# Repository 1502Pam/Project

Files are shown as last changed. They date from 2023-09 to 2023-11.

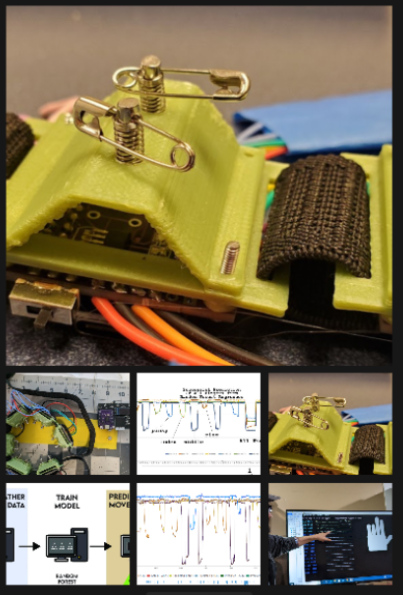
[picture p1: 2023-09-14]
Imágenes/muscle_finger.png

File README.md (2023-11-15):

# Equipo 12

#### Bienvenidos al repositorio del Equipo 12 del curso Fundamentos de Biodiseño

<image src ="Imágenes/foto_grupal_2.jpg"> 

## Tabla de contenido

- [Roles de los integrantes del proyecto](#Roles-de-los-integrantes-del-proyecto).
- [Análisis del caso clínico](#Análisis-del-caso-clínico).
- [Clínica de problemáticas en salud](#Clínica-de-problemáticas-en-salud).
- [Problemática](#Problemática).
- [Estado del arte científico](#Estado-del-arte-científico).
- [Estado del arte comercial](#Estado-del-arte-comercial).
- [Lista de requerimientos](#Lista-de-requerimientos).
- [Propuesta de solución](#Propuesta-de-solución).
- [Caja negra](#Caja-negra).
- [Esquema de funciones](#Esquema-de-funciones).
- [Matriz morfológica](#Matriz-morfológica).
- [Tabla de valoración](#Tabla-de-valoración).
- [Conclusión-del-CS](#Conclusión-del-CS).
- [Bocetos](#Bocetos).
- [Docentes del curso](#Docentes-del-curso).
- [Bibliografía](#Bibliografía).

## Roles de los integrantes del proyecto
- Chavez Rivas Allen Stirs (Planificador de la electrónica)
- Lazares Salcedo, Brayam Joe (Planificador de diseño de los planos del prototipo)
- Llanos Florian Dhiago Gustavo (Coordinador del grupo y planificador del modelado 3D del prototipado)
- Medina Burga Yuliana Abigail (Planificador de manufactura digital)
- Sanchez Valverde Mariel Linette (Planificador de programación)
- Vilchez Cotrina Pamela Nicole (Planificador del repositorio Github)

## Análisis del caso clínico

### A) Contexto

Según Global Burden of Disease (GBD)<sup>[1](https://vizhub.healthdata.org/gbd-results?params=gbd-api-2019-permalink/5ed2741ada3f6d3537da4bec76913a24)</sup>, existe una prevalencia mundial de amputaciones cercana a 500 millones de personas entre los periodos 1990 y 2019.

<image src ="Imágenes/B1.png"> 
   
###### Figura 1: Gráfica de prevalencia de amputaciones en personas mayores a 25 años desde 1990 hasta 2019 a nivel global. Obtenido del GBD

Inclusive los números han ido en crecimiento; por ende, se estima que, para este año 2023, la cifra habrá sobrepasado los 500 millones de personas mayores a 25 años con algún tipo de amputación.

<image src ="Imágenes/B2.png"> 
   
###### Figura 2: Gráfica de prevalencia del tipo de amputaciones en personas mayores a 25 años en el período 1990-2019 a nivel global. Obtenido del GBD

El tipo de amputación más común es en dedos, con una prevalencia que supera los 300 millones casos y que representa el 69.71% de las amputaciones totales, según los datos otorgados por el GBD. Además, la gráfica hace una clara diferencia entre los dedos y el pulgar, esto puede deberse a una mayor importancia del pulgar sobre los demás dedos.

<image src ="Imágenes/B3.png"> 

###### Figura 3: Gráfica de prevalencia en el período 1990-2019 e incidencia del año 2019 de amputaciones en el pulgar a nivel global. Obtenido del GBD

En cuanto a la estadística de amputaciones del pulgar, el 21.8% de amputaciones totales de dedos son de pulgares. Además, la incidencia de este tipo de amputación, en el año 2019, fue superior a un millón a nivel global.

<image src ="Imágenes/B4.png"> 

###### Figura 4: Gráfica de prevalencia en el período 1990-2019 e incidencia del año 2019 de amputaciones del pulgar en Latinoamérica. Obtenido del GBD

A nivel de Latinoamérica, se tiene una prevalencia superior a los 9 millones y una incidencia, en 2019, de 128000 personas con amputaciones del pulgar. A partir de la gráfica, se aprecia que la zona andina de países como Perú, Bolivia y Ecuador tiene la menor estadística; no obstante, el tamaño de población de cada una es inferior respecto al resto de regiones latinoamericanas.

<image src ="Imágenes/B5.png"> 

###### Figura 5: Prevalencia de amputaciones del pulgar a nivel global en el período 1990-2019. Obtenido del GBD.
   
En el Perú, existe una prevalencia de 400 mil personas con amputaciones de dedo en el período 1990-2019; además, según el Boletín Estadístico Mensual de Notificaciones de accidentes de Trabajo, Incidentes Peligrosos y Enfermedades Ocupacionales, durante el mes de abril del 2023, se reportaron 2390 personas que sufrieron accidentes de trabajo, destacando los siguientes datos<sup>[2](https://cdn.www.gob.pe/uploads/document/file/4811002/SAT_MARZO_2023_opt.pdf?v=1688742640), [3](https://cdn.www.gob.pe/uploads/document/file/4811381/SAT_ABRIL_2023_opt.pdf?v=1688744828)</sup> : 

| Accidentes de trabajo | Especificación | Cantidad de personas afectadas | Fecha de registro de datos |
| --- | --- | --- | --- |
| Agente causante  | Generador de energía excepto motores eléctricos | 10 | Marzo 2023 |
| | Contacto con la corriente eléctrica  | 13 | Marzo 2023 |
| Naturaleza de la lesión | Amputación | 20 | Marzo 2023 |
| Parte del cuerpo afectada | Dedos de la mano | 411 | Abril 2023 |
|  | Mano (excepción de los dedos solos) | 139 | Abril 2023 |
| Naturaleza de la lesión | Amputación | 13 | Abril 2023 |
| Agente causante | Instalaciones eléctricas, incluidos los motores eléctricos pero con exclusión de las herramientas eléctricas manuales | 1 | Abril 2023 |
###### Tabla 1: Tabla de accidentes de trabajo del mes de abril y marzo 2023. Elaboración ia en base a datos obtenidos del Ministerio de Trabajo y Promoción del Empleo

En el mes indicado, 411 personas sufrieron de amputaciones de dedos; es decir, en aproximadamente 137 casos, el pulgar fue amputado. Este dato es muy significante, puesto que la amputación del pulgar resulta en una pérdida del 40% de las funciones de la mano y en un 22% de la función total de la persona<sup>[4](https://doi.org/10.1016/j.hcl.2020.09.013), [5](https://journals.sagepub.com/doi/abs/10.1177/1558944721999734)</sup>.

### B) Consecuencias de un pulgar amputado

#### 1. Síndrome del miembro fantasma
   
Perder una parte del cuerpo desencadena una serie de consecuencias funcionales psicológicas y fisiológicas<sup>[4](https://doi.org/10.1016/j.hcl.2020.09.013)</sup>; de hecho, la consecuencia más común y conocida es el síndrome del miembro fantasma. Entre un 60-80% de los usuarios amputados experimentan sensación de dolor del miembro fantasma, donde el 95% de estos reportan experimentar dolor en las primeras semanas posteriores a la amputación y el 60-70% después de un año de la amputación<sup>[6](https://doi.org/10.1016/j.cjtee.2018.04.006)</sup>.

| Clasificación de la sensación de dolor | Descripción |
|---|---|
| Dolor en el miembro residual  | Percepción dolorosa en el segmento no amputado |
| Sensación fantasma | Percepción no dolorosa del segmento amputado |
| Dolor del miembro fantasma | Percepción dolorosa en el segmento amputado |
###### Tabla 2: Clasificación de la sensación de dolor en el síndrome del miembro fantasma. Elaboración ia en base a los datos de la investigación de Kaur A. & Guan Y.

Por otro lado, existen factores fundamentales que determinan la sensación de dolor:

| Factores |  | Descripción |
|---|---|---|
| Factores periféricos  | Actividad de los nervios residuales | Se presenta degeneración retrógrada y acortamiento de las neuronas aferentes, las cuales generan neuromas que incrementan la sensibilización a los estímulos |
| Factores centrales | Plasticidad espinal | Posterior a la lesión de un nervio periférico, las neuronas del cuerno posterior de la médula espinal muestran sensibilización central; es decir, estímulos nociceptivos de corta duración generan potenciales postsinápticos aumentados durante un largo período de tiempo.|
| | Reorganización cortical | Las áreas neuronales adyacentes de la zona cortical que representaba el miembro amputado, presenta cambios de neuroplasticidad sobre la corteza motora primaria (M1) y somatosensorial primaria (S1). | 
###### Tabla 3: Factores de riesgo de dolor de miembro fantasma. Elaboración ia en base a la información de Kaur A. & Guang Y.

Por tales factores, el miembro fantasma depende de muchos cambios neurológicos causados por un cambio drástico en la anatomía del miembro amputado. En el caso del pulgar, estos cambios podrían variar o ser más complejos debido al rol del pulgar en la anatomía y fisiología de la mano.

#### 2. Merma del movimiento de la mano

El movimiento de la mano tiene un total de 25 grados de libertad (GDL) y se describe en el campo biomecánico por un conjunto de ángulos de rotación fisiológicos: flexión/extensión (F/E), abducción/aducción (Ab/Ad) y pronación/supinación (P/S)<sup>[7](http://www.xixcnim.uji.es/CDActas/Documentos/ComunicacionesPosters/01-13.pdf)</sup>.

<image src ="Imágenes/1M_n.jpeg"> 

###### Figura 6: Movimientos de la mano. Obtenido de la Asociación Española de Ingeniería Mecánica.

Además, el movimiento de la mano es producido por los músculos extrínsecos e intrínsecos, destacando a este último por su ubicación en la región de la muñeca y por la produccción de los movimientos del pulgar: abducción, aducción, flexión y oposición<sup>[8](https://revistas.unal.edu.co/index.php/morfolia/article/view/31373/31379)</sup>.
Cabe resaltar que la articulación del pulgar funciona básicamente con dos GDL predominantes (F/E y Ab/Ad); sin embargo, al amputarse este miembro, se pierden todos los movimientos del pulgar, mermando así los ángulos de rotación de la mano.

#### 3. Pérdida de los agarres de fuerza

Los agarres de fuerza crean patrones motores y señales nerviosas que originan el movimiento que deseamos. De esta manera, cuando la amputación se da en el pulgar, se desencadenan problemas como la hiperestesia<sup>[9](https://www.jhandtherapy.org/article/S0894-1130(22)00003-5/fulltext)</sup> y la pérdida de agarre de fuerza, el cual se clasifica en cilíndrico, esférico, gancho, precisión, palmar y lateral<sup>[10](https://ieeexplore.ieee.org/document/6610858), [11](https://www.oandplibrary.org/al/pdf/1955_02_022.pdf)</sup>.

<image src ="Imágenes/3M_n.jpeg"> 

###### Figura 7: Clasificación de los distintos agarres de fuerza. Obtenido de Taylor, C. & Schwarz, R.

### C) Alternativas de solución actuales ante la amputación de un miembro

En la actualidad, la mejor forma de adaptarse a realizar las mismas actividades de trabajo tras una amputación es a través del uso de una prótesis, puesto que está asociada con la disminución en la sensación del miembro fantasma y dolor en el miembro residual<sup>[4](https://doi.org/10.1016/j.hcl.2020.09.013)</sup>. Además, la fuerza desorcionada en los miembros residuales se trabaja con rutinas de terapia, con el fin de enseñar al usuario a mantener las articulaciones en la posición adecuada<sup>[4](https://doi.org/10.1016/j.hcl.2020.09.013)</sup>. 

Para ello, existen 4 técnicas que permiten el ajuste del posicionamiento de una prótesis con el muñón<sup>[12](https://www.msdmanuals.com/es-pe/professional/temas-especiales/miembro-prot%C3%A9sico/opciones-para-las-pr%C3%B3tesis-de-los-miembros)</sup>. : al vacío, correas, succión e interfaz con traba. Dependiendo del tipo de movimiento y situación del usuario, se suelen fusionar con almohadillas de gel y medias protésicas. No obstante, este posicionamiento también puede depender del tipo de prótesis y sus diferentes funcionalidades<sup>[13](https://pubmed.ncbi.nlm.nih.gov/34043536/), [14](https://www.healthquality.va.gov/guidelines/Rehab/ULA/VADoDULACPG_ProviderSummary_Final_508.pdf)</sup>.

| Prótesis | Descripción | Tasa de abandono |
| --- | --- | --- |
| Prótesis funcional pasiva | <p> - Aumenta la longitud digital. <p> - Restaura la cosmosis y mejora el desempeño general de la mano. <p> - Suelen estar hechos de silicona | 100% |
| Prótesis impulsadas por el cuerpo (Body-Powered) | <p> - Aprovechan la anatomía restante de la amputación. <p> - Independientes de baterías externas o electricidad. <p> - Sincrónico con movimientos naturales de la mano. <p> - Limitaciones cosméticas (alto grado de mantenimiento y peso excesivo) | 80-85% |
| Prótesis impulsadas externamente (Externally-Powered) | <p> - Ideales para amputaciones trans-metacarpianas. <p> - Destacan las mioeléctricas (MYO) que registran señales de electromiografía de superficie. <p> - Logra posturas de agarre de forma independiente y sincronizada. | 75% |
| Prótesis para actividades específicas | <p> - Destinadas a varios tipos de amputaciones. <p> - Limitación a una única función a suplir. <p> - Preferido como herramienta de asistencia en lugar de reemplazo del bro amputado | |
###### Tabla 4: Tipos de prótesis y tasa de abandono. Elaboración ia a partir de datos los documentos [13](https://pubmed.ncbi.nlm.nih.gov/34043536/) y [14](https://www.healthquality.va.gov/guidelines/Rehab/ULA/VADoDULACPG_ProviderSummary_Final_508.pdf).

Sin embargo, la principal razón para el abandono de estos cuatro tipos de prótesis es el precio, el cual puede llegar a ser entre 5000 a 12000 dólares; por consiguiente, siendo poco asequible para muchos usuarios amputados. Pese a ello, la manufactura aditiva es el último avance en el campo del diseño protésico, pues es capaz de fabricar prótesis de bajo costo y menor peso. La característica principal de esta es su tecnología de fabricación aditiva, donde los productos son construidos agregando capa por capa en una placa de construcción para producir el producto final; otorgando como principal ventaja la capacidad de orcionar una alta relación resistencia-peso a través de un relleno configurable<sup>[14](https://www.healthquality.va.gov/guidelines/Rehab/ULA/VADoDULACPG_ProviderSummary_Final_508.pdf)</sup>.

## Clínica de problemáticas en salud

El usuario presenta sensación de miembro fantasma y dolor persistente; por tal motivo, es necesario tomar medidas para fortalecer la musculatura residual y favorecer actividades uni/bimanuales para facilitar sus actividades de vida diarias.

Además, existen diversos problemas de los miembros inferiores en la amputación transtibial: marcha compensada, alteración sensorial táctil y dificultad para reconocer un adecuado punto de apoyo. 

Por otro lado, en cuanto a los miembros superiores, se distinguen las siguientes dificultades tras la amputación transmetacarpiana y desarticulación interfalángica proximal del dedo medio: dolor palpable a nivel de musculatura interósea y lumbricales, control inadecuado de la presión palmar, movimiento mínimo del músculo oponente del pulgar y fuerza de presión disminuída.

## Problemática

Hay una deficiencia de prótesis de pulgar especializados en el agarre de fuerza en el mercado peruano.

## Estado del arte científico
1. Diseño de brazalete EMGs en prótesis de mano para reducción de costos<sup>[13](https://www.sciencedirect.com/science/article/abs/pii/S0208521619304693)</sup>.

Se llevó a cabo una investigación de diferentes tipos de prototipos de prótesis de mano, en la que se evaluaron los elementos utilizados para su respectivo funcionamiento, la metodología empleada para un mejor control y el costo de fabricación. El prototipo ganador fue desarrollado por Krausz et al. Su diseño se basa en una mano de seis grados de libertad y es de código abierto. A partir de este prototipo, se buscó optimizarlo mediante cambios en los dispositivos de transmisión de potencia y actuación con el fin de reducir costos y mejorar la funcionalidad.
El procesamiento de los datos EMG se obtendrá a través de un hardware portátil basado en la arquitectura maestro-esclavo. Como dispositivo maestro, se utilizará un sistema basado en Raspberry Pi interconectado con el brazalete EMG, que recopilará y clasificará el movimiento. Como dispositivo esclavo, se empleará un microcontrolador ATmega328 que definirá los movimientos recopilados y procesados por el dispositivo maestro.

<image src ="https://github.com/1502Pam/Project/blob/69620e2351e32556382e2b7bd61a9802c00276ee/Im%C3%A1genes/R1.jpg"> 

2. Construcción de músculos neumáticos<sup>[15](https://www.sciencedirect.com/science/article/abs/pii/S0957415816301532)</sup>.

Se presenta una metodología para la construcción de músculos neumáticos. Para evaluar la funcionalidad de este proyecto, se desarrolló un dedo mecatrónico que, al igual que un dedo humano convencional, consta de tres falanges. Este dedo posee dos características distintivas: funcionalidad y antropomorfismo. Se llevaron a cabo pruebas tanto con carga como sin ella, y se observó que los movimientos de los dedos fueron suaves y precisos.
Para controlar el movimiento de cada articulación, se obtuvieron las ecuaciones cinemáticas directas e inversas, las cuales se ajustaron a controladores tipo PID. Para medir la posición angular de cada articulación, se emplearon sensores de efecto Hall.
El uso de músculos neumáticos se presenta como una alternativa a los actuadores convencionales, como solenoides o motores (tales como motores de corriente continua y servomotores, entre otros). Los músculos neumáticos requieren presiones de aire del orden de 3 a 6 bares para generar fuerzas que van desde 30 hasta incluso 1000N. Un músculo neumático es un actuador de tracción, ya que se contrae y expande de manera similar a un músculo biológico. Este músculo está compuesto por un material elástico homogéneo recubierto por fibras retorcidas, creando una estructura similar a una red. La presión de aire se aplica como entrada para lograr su funcionamiento.

<image src ="https://github.com/1502Pam/Project/blob/69620e2351e32556382e2b7bd61a9802c00276ee/Im%C3%A1genes/R2.jpg"> 

3.Diseño de prótesis para discapacitados por conflictos bélicos<sup>[16](https://pubmed.ncbi.nlm.nih.gov/29196160/)</sup>.
   
Se ha creado una mano protésica utilizando técnicas electromiográficas. Su segunda función es aprender a percibir objetos para determinar la cantidad de presión que debe ejercer. El sensor muscular captura las señales del músculo humano, y estas señales se transmiten al microcontrolador. Este último, basándose en algoritmos preprogramados, genera una señal de salida que se utiliza para controlar el actuador robótico suave, el cual emplea un mecanismo de bombeo.
El material seleccionado para la construcción es el PLA debido a su ligereza y capacidad de aplicar presión. Aunque se consideraron nanofibras de carbono, se descartaron debido a su impacto en el costo de fabricación.
En relación al microcontrolador, se utiliza para gestionar las acciones y la presión aplicada por el actuador. En el caso de los actuadores neumáticos, se emplea el sistema Pneunet, controlado mediante microhidráulica. Este mecanismo de inyección de fluido es accionado por un motor que empuja el pistón, suministrando así el fluido necesario para activar el actuador y lograr el agarre. Una vez finalizada la acción, el pistón regresa a su posición de equilibrio, lo que devuelve el fluido al actuador Pneunet. Los autores han optado por la hidráulica debido a la complejidad de tratar con la compresión del aire, asegurando así que el sistema pueda determinar la cantidad de fuerza a aplicar sin dañar el objeto.
El mecanismo se considera "sencillo" debido a que la mano no cuenta con un mecanismo de sensibilidad comparable a la piel humana. En cambio, los ojos asumen esta función, detectando el material a manipular. El cerebro genera señales que se transmiten a los músculos de la mano, donde son detectadas por sensores musculares, activando el mecanismo previamente mencionado.

<image src ="https://github.com/1502Pam/Project/blob/69620e2351e32556382e2b7bd61a9802c00276ee/Im%C3%A1genes/R3.jpg"> 
   
## Estado del arte comercial

### A) Equipos o dispositivos existentes en el mercado

|| Dispositivos existentes en el mercado ||
| --- | --- |--- |
| GripLock Finger<sup>[17](https://www.npdevices.com/wp-content/uploads/2022/01/GripLock-Finger-Solo-Sheet-English-Dec-20-2021-edge-.pdf)</sup> | THUMBDriver<sup>[18](https://www.npdevices.com/wp-content/uploads/2022/01/ThumbDriver-Solo-Sheet-English-Dec-20-2021-edge.pdf)</sup> | PIPDriver<sup>[19](https://www.npdevices.com/wp-content/uploads/2022/01/PIPDriver-Solo-Sheet-English-Dec-20-2021-edge.pdf)</sup> |
| <image src ="Imágenes/griplock.png"> | <image src ="Imágenes/thumbdriver.png"> | <image src ="Imágenes/PIPdriver.png"> |
| Dedo protésico para la falange media, de bloqueo pasivo y posicionable, diseñado para ser laminado en un encaje parcial a medida. Está diseñado para soportar con firmeza más de 90.71kg en agarre de gancho. | Diseñado para la falange proximal del pulgar. Al igual que el MCP driver este dispositivo se acciona mediante una articulación MCP (metacarpofalángica), pero especialmente en actividades para el pulgar. Gracias al diseño el dispositivo se adapta a las necesidades del usuario, esto facilita la realización de pellizco y agarre.|Diseñada para extremidades parciales y dedos en la falange media o distal. Su diseño se adapta a las articulaciones PIP (distal interfalángica) y DIP (proximal interfalángica). Acciona mediante una articulación PIP intacta con suficiente residuo para encajar la jaula. Esto hace que la estructura en forma de jaula proteja el residuo(muñón). |
| Materiales: <p> - nylon 12 (medical grade) <p> - silicona <p> - aluminio 7075-T6 <p> Resistencia al calor: <p> - nylon 175 C <p> - silicona 204.4C | Materiales: <p> - nylon 12 (medical grade) <p> - silicona <p> - stainless 316 <p> - titanio <p> Resistencia al calor: <p> - nylon 175 C <p> - silicona 204.4 C <p> Resistencia a la tensión del anillo: <p> - 36.28kg | Materiales: <p> - nylon 12 (grado médico) <p> - silicona <p> - titanio <p> Resistencia al calor: <p> - nylon 175 C <p> - silicona 204.4 C <p> Resistencia al aplastamiento: <p> - mayor a 27.22kg |

### B) Patentes de invención y Patentes de modelo de utilidad

|| Invención|| Utilidad |
| --- | --- |--- |--- |
| Prótesis mioeléctrica y método<sup>[20](https://patents.google.com/patent/US10376389B2/en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)</sup>	| Prótesis de mano multifuncional y autónoma<sup>[21](https://worldwide.espacenet.com/patent/search?q=pn%3DES2571880T3)</sup>	| Una prótesis de mano<sup>[22](https://worldwide.espacenet.com/patent/search?q=pn%3DWO2022132105A1)</sup>	| Prótesis trans de articulación de muñeca y pulgar impresora 3D<sup>[23](https://worldwide.espacenet.com/patent/search?q=pn%3DCN218652141U)</sup> |
| <image src ="Imágenes/protesis_mioeléctrica.png"> | <image src ="Imágenes/protesis_multifuncional.png"> | <image src ="Imágenes/protesis_mano.png"> | <image src ="Imágenes/protesis_trans.png"> |
| Gaston y Loeffler -Estados Unidos (2017) | Controzzi, Clemente, Cipriani, Carrozza - España (2016) | HOCAOĞLU ÇETİNSOY – Turkia (2022) | Wei Qipei; Liu Chang; Yang Chen; Chen Shanlin – China (2023) |
| Es una próstesis de trasferencia de señales con electrodos, describe con exactitud la conexión de cada uno de los nervios que generan el movimiento de los músculos en la mano. Utiliza microprocesadores multicanal, entradas EMG, motores, etc., es el mayor avance para las prótesis mioeléctricas. El ensamblado al paciente es un método quirúrgico. | Prótesis de mano que permite la rotación, abducción y flexión del dedo, a partir de un sistema eléctrico y árbol motor rotativo que están programados para el movimiento restringido, a partir del análisis del movimiento angular. Utilizan el mecanismo rotativo de cruz de malta y una línea de trasmisión del movimiento. | Se utiliza señales electromiografías de superficie y polímeros que tiene memoria elástica y que cambian su rigidez dependiendo de factores externos. Dividen la estructura tres huesos con poleas y calentadores. EL movimiento lo generan motores DC de control, no se utiliza ningún tipo de algoritmo, es de bajo costo, gran adaptabilidad al amputado, lo que reduce el tiempo de rehabilitación. | A otras modelos de prótesis 3D se incluye una bola, tapa y varilla metacarpiana que se conectan por rosca con los otros huesos y la varilla se coloca en una posición alejada mejorando el uso técnico de la prótesis. Utiliza materiales como polietileno, cromo de cobalto, aleación de aluminio biológicamente compatibles. |

## Lista de requerimientos
### Funcionales
- Realizar y regular el agarre de fuerza necesario para permitir la reinserción laboral.
- Permitir el movimiento circundal del pulgar.
- Medir los ángulos de los dedos restantes de la mano para ajustar su movimiento.
- Almacenar energía en una bateria.

### No Funcionales
- Ergonómico
- Tamaño orcional al paciente
- Ligero
- Accesible
- Poseer la fricción necesaria para evitar el deslizamiento de objetos.
- Portátil 

## Propuesta de solución
Pulgar mioeléctrico protésico, apoyado por un músculo neumático, diseñado para restaurar el agarre de fuerza y el movimiento parcial de este miembro.

## Docentes del curso

- Paulo Camilo Alberto Vela Anton
- Renzo Jose Chan Rios
- Umberto Lewis De la Cruz Rodriguez
- Juan Manuel Zuñiga Mamamni
- Jose Alonso Caceres del Aguila
- Andres Arturo Rodriguez De Velasco
- Yeni Varillas Tacza

## Bibliografía 
1. Global Health Data Exchange. Global Burden of Disease [internet]. 2019 [Citado 13 Sep 2023]. Disponible en: https://vizhub.healthdata.org/gbd-results?params=gbd-api-2019-permalink/5ed2741ada3f6d3537da4bec76913a24
2.	Ministerio de Trabajo y Promoción del Empleo. Notificaciones de accidentes de trabajo, incidentes peligrosos y enfermedades ocupacionales BOLETÍN ESTADÍSTICO MENSUAL MARZO 2023 [Internet]. 2023 [citado 30 de agosto de 2023]. Disponible en: https://cdn.www.gob.pe/uploads/document/file/4811002/SAT_MARZO_2023_opt.pdf?v=1688742640
3.	Ministerio de Trabajo y Promoción del Empleo. Notificaciones de accidentes de trabajo, incidentes peligrosos y enfermedades ocupacionales BOLETÍN ESTADÍSTICO MENSUAL ABRIL 2023 [Internet]. 2023 [citado 30 de agosto de 2023]. Disponible en: https://cdn.www.gob.pe/uploads/document/file/4811381/SAT_ABRIL_2023_opt.pdf?v=1688744828
4.	Graham EM, Hendrycks R, Baschuk CM, Atkins DJ, Keizer L, Duncan CC, et al. Restoring Form and Function to the Partial Hand Amputee: Prosthetic Options from the Fingertip to the Palm [Internet]. Vol. 37, Hand Clinics. W.B. Saunders; 2021 [citado 30 de agosto de 2023]. p. 167-87. Disponible en: https://doi.org/10.1016/j.hcl.2020.09.013
5.	Deivasigamani S, Azad A, Yang SS. The Variable Insertional Anatomy of the Abductor Pollicis Longus: Functional Relevance and Relationship to Adjacent Thumb Extensors. Hand [Internet]. 1 de enero de 2023 [citado 30 de agosto de 2023];18(1):145-52. Disponible en: https://journals.sagepub.com/doi/abs/10.1177/1558944721999734
6.	Kaur A, Guan Y. Phantom limb pain: A literature review [Internet]. Vol. 21, Chinese Journal of Traumatology - English Edition. Elsevier B.V.; 2018 [citado 12 de septiembre de 2023]. p. 366-8. Disponible en: https://doi.org/10.1016/j.cjtee.2018.04.006
7.	Bru JLS, Vergara M, Jarque Bou NJ, Aguilar MM, Pérez González A. Asociación Española de Ingeniería Mecánica XIX CONGRESO NACIONAL DE INGENIERÍA MECÁNICA Medición del movimiento de todos los segmentos de la mano mediante videogrametría [Internet]. 2012 [citado 12 de septiembre de 2023]. Disponible en: http://www.xixcnim.uji.es/CDActas/Documentos/ComunicacionesPosters/01-13.pdf
8.	Arias López LA. Biomecánica y patrones funcionales de la mano [Internet]. Vol. 4. 2012 [citado 12 de septiembre de 2023]. Disponible en: https://revistas.unal.edu.co/index.php/morfolia/article/view/31373/31379
9.	van Heijningen VG, Underhill A. User experiences of digital prostheses in daily functioning in people with an amputation of thumb or finger. Journal of Hand Therapy [Internet]. 1 de abril de 2022 [citado 30 de agosto de 2023];35(2):289-98. Disponible en: https://www.jhandtherapy.org/article/S0894-1130(22)00003-5/fulltext
10.	IEEE Engineering in Medicine and Biology Society, Annual International Conference of the IEEE Engineering in Medicine and Biology Society 35 2013.07.03-07 Osaka, EMBC 35 2013.07.03-07 Osaka, EMBS Annual Conference 35 2013.07.03-07 Osaka. 2013 35th annual international conference of the IEEE Engineering in Medicine and Biology Society (EMBC) 3-7 July 2013, Osaka, Japan [Internet]. 2013 [citado 12 de septiembre de 2023]. Disponible en: https://ieeexplore.ieee.org/document/6610858
11.	Taylor CL, Schwarz RJ. The Anatomy and Mechanics of the Human Hand [Internet]. 1955 [citado 12 de septiembre de 2023]. Disponible en: https://www.oandplibrary.org/al/pdf/1955_02_022.pdf
12.	Jan J. Stokosa. Opciones para las prótesis de los miembros. En: Manual MSD. 2021. 
13.	Kieliba P, Clode D, Maimon-Mor RO, Makin TR. Robotic hand augmentation drives changes in neural body representation [Internet]. Vol. 6, Sci. Robot. 2021. Disponible en: https://pubmed.ncbi.nlm.nih.gov/34043536/(https://www.sciencedirect.com/science/article/abs/pii/S0208521619304693)
14.	Lewin Group T. VA/DoD_Clinical_Practice_Guidelines:_Management_of_Upper_Limb_Amputation_Rehabilitation_Provider_Summary [Internet]. 2022. Disponible en: https://www.healthquality.va.gov/guidelines/Rehab/ULA/VADoDULACPG_ProviderSummary_Final_508.pdf
15.	Oliver-Salazar MA, Szwedowicz-Wasik D, Blanco-Ortega A, Aguilar-Acevedo F, Ruiz-González R. Characterization of pneumatic muscles and their use for the position control of a mechatronic finger. Mechatronics (Oxf) [Internet]. 2017;42:25–40. Disponible en: https://www.sciencedirect.com/science/article/pii/S0957415816301532
16.	Sayar H, Karajagikar J, Deshmukh S. Prosthetic limb arm for armless human. Mater Today [Internet]. 2023;72:1056–60. Disponible en: https://www.sciencedirect.com/science/article/pii/S221478532205982X
17.	Npdevices.com. [citado el 21 de septiembre de 2023]. Disponible en: https://www.npdevices.com/wp-content/uploads/2022/01/GripLock-Finger-Solo-Sheet-English-Dec-20-2021-edge-.pdf
18. Robust A, solution. F. ThumbDriver | 2nd GENERATION [Internet]. Npdevices.com. [citado el 21 de septiembre de 2023]. Disponible en: https://www.npdevices.com/wp-content/uploads/2022/01/GripLock-Finger-Solo-Sheet-English-Dec-20-2021-edge-.pdf
19. Robust A, solution. F. PIPDriver | 2nd GENERATION [Internet]. Npdevices.com. [citado el 21 de septiembre de 2023]. Disponible en: https://www.npdevices.com/wp-content/uploads/2022/01/PIPDriver-Solo-Sheet-English-Dec-20-2021-edge.pdf
20. Gaston, G y Loeffler, B. Prótesis mioeléctrica y método [Patente]. Estados Unidos: 2017. Disponible en: [US10376389B2 - Myoelectric prosthesis and method - Google Patents](https://patents.google.com/patent/US10376389B2/en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)
21. Controzzi, Clemente, Cipriani, Carrozza. Prótesis de mano multifuncional y autónoma. [Patente]. España: 2016. Disponible en: https://worldwide.espacenet.com/patent/search?q=pn%3DES2571880T3
22. HOCAOĞLU ÇETİNSOY. Una prótesis de mano. [Patente]. Turkia: 2022. Disponible en: https://worldwide.espacenet.com/patent/search?q=pn%3DWO2022132105A1
23. Qipei, W. Chang, L. Chen, Y. Shanlin, C. Prótesis trans de articulación de muñeca y pulgar impresora 3D. [Patente]. China: 2023. Disponible en: https://worldwide.espacenet.com/patent/search?q=pn%3DCN218652141U

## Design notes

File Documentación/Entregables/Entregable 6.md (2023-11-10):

<h1> Carcasa 1.1V </h1>
<image src ="https://github.com/1502Pam/Project/blob/main/Im%C3%A1genes/carcasa%201.1V.jpeg"> 
  
<h1> Carcasa 1.2V </h1>
<image src ="https://github.com/1502Pam/Project/blob/main/Im%C3%A1genes/carcasa%201.2V.jpeg"> 
  
<h1> Pulgar </h1>
<image src ="https://github.com/1502Pam/Project/blob/main/Im%C3%A1genes/pulgar.jpeg"> 

Link OnShape
https://cad.onshape.com/documents/3dd639875da624873c76d255/w/840f5bff105d4cd6ea5c74b6/e/706700bb52c3b1448e8044bc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

<h1> Diseño esquemático del circuito electrónico </h1> 

<image src ="https://github.com/1502Pam/Project/blob/main/Im%C3%A1genes/now.jpeg"> 

<h1> Código de programación </h1> 

## Código de programación sensor FSR - micromotor de vibración

<image src ="https://github.com/1502Pam/Project/blob/main/Im%C3%A1genes/c%C3%B3digo_sensorFSR.jpeg"> 

## Código de programación sensor EMG - minibomba de aire - 2 microválvulas

<image src ="https://github.com/1502Pam/Project/blob/main/Im%C3%A1genes/codigo_EMG1_act.jpeg"> 
<image src ="https://github.com/1502Pam/Project/blob/main/Im%C3%A1genes/codigo_EMG2.jpeg"> 

<h1> Diagrama de flujo </h1> 
<image src ="https://github.com/1502Pam/Project/blob/cb11ef39444757008514c5fd22432613eeb8262e/Im%C3%A1genes/flowchart%20.png"> 

<h1> Video </h1> 

https://github.com/1502Pam/Project/assets/143039675/48213393-76ca-4721-b0cd-c3cb8b63df7f

https://github.com/1502Pam/Project/assets/143039675/e65b3c93-5101-48c0-b037-f210772002e8

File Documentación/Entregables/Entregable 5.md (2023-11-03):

<h1> Esquema Electrónico del concepto de solución </h1> 

<image src ="https://github.com/1502Pam/Project/blob/main/Im%C3%A1genes/Esquema_electronico_actualizado.png">

## Modelado 3D de los componentes por separado

* Link a OneShape: 
*https://cad.onshape.com/documents/3dd639875da624873c76d255/w/840f5bff105d4cd6ea5c74b6/e/bcf3e5e2e9629e0099b93e7d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*

* Link a SketchFab:
*https://sketchfab.com/TuMother777*

### Pulgar protésico
<image src ="https://github.com/1502Pam/Project/blob/main/Im%C3%A1genes/pulgar_prot%C3%A9sico.jpeg">

### Tubo de aire
<image src ="https://github.com/1502Pam/Project/blob/main/Im%C3%A1genes/tubo_de_aire.jpeg">

### Soporte de antebrazo
<image src ="https://github.com/1502Pam/Project/blob/main/Im%C3%A1genes/soporte_de_antebrazo.jpeg">

### Soporte de pulgar
<image src ="https://github.com/1502Pam/Project/blob/main/Im%C3%A1genes/soporte_pulgar.jpeg">

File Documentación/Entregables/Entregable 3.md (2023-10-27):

## Caja negra

<image src ="https://github.com/1502Pam/Project/blob/main/Im%C3%A1genes/caja_negra.jpeg"> 

## Esquema de funciones

<image src ="https://github.com/1502Pam/Project/blob/main/Im%C3%A1genes/esquema_funciones.jpeg"> 

## Matriz morfológica 

<image src ="https://github.com/1502Pam/Project/blob/main/Im%C3%A1genes/matriz_3.png">

## Tabla de valoración

| N° | Criterios | CS1 | CS2 | CS3 |
|---|---|---|---|---|
| 1 |Funcionalidad|4|**3**|3|
| 2 |Nivel de Innovacion|4|**3**|2|
| 3 |Seguridad|3|**2**|2|
| 4 |Disponibilidad de repuestos|4|**3**|2|
| 5 |Durabilidad|3|**3**|2|
| 6 |Ligereza|3|**2**|2|
| 7 |Portabilidad|4|**1**|3|
| 8 |Posibilidad de automatización|3|**3**|3|
| 9 |Gasto energético|3|**1**|4|
| 10 |Costo de tecnología|4|**1**|2|
|----|Suma total| 35 | **22** | 25 |

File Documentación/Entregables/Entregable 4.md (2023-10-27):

## Bocetos

### Título del proyecto: Prótesis del dedo pulgar, boceto preliminar 1

Dibujado por: Pamela Nicole Vilchez Cotrina

<image src ="https://github.com/1502Pam/Project/blob/main/Im%C3%A1genes/boceto_1.png">
<image src ="https://github.com/1502Pam/Project/blob/d548697ae5ded7039d95619e3da58f1ed4b2ea82/Im%C3%A1genes/boceto_1.1.png">

Lista de despiece
<image src ="https://github.com/1502Pam/Project/blob/main/Im%C3%A1genes/Despiece_1.1.png">

Descripción del funcionamiento

La prótesis del dedo pulgar recibe la señal captada por el sensor EMG, y es procesada por el arduino nano every el cual es alimentada por baterías de 9V. Además, la prótesis presenta una bomba peristáltica el cual impulsa su movimiento a través del músculo neumático por un tubo de aire. Para proteger los componentes electrónicos y mecánicos del sistema, se ha aplicado una cubierta de resina flexible.

### Título del proyecto: Prótesis del dedo pulgar, boceto preliminar 2
Dibujado por: Brayam Joe Lazares Salcedo

<image src ="https://github.com/1502Pam/Project/blob/main/Im%C3%A1genes/boceto_2.jpg">

Lista de despiece

<image src ="https://github.com/1502Pam/Project/blob/main/Im%C3%A1genes/Despiece2.jpg">

Descripción del funcionamiento

El dispositivo incorpora un sensor de electromiografía (EMG) situados en el músculo del pulgar flexor corto. Estos sensores envían señales hacia el nano Arduino para ser procesados. Este último componente, a su vez, controlará los movimientos de la prótesis del pulgar derecho mediante la comprensión de un músculo neumático, cuyo suministro es una bomba peristáltica. Todo el sistema está integrado en un guante flexible y agradable al tacto cuyo funcionamiento depende de baterías de litio recargables directamente

### Título del proyecto: Prótesis del dedo pulgar, boceto preliminar 3

<image src ="https://github.com/1502Pam/Project/blob/main/Im%C3%A1genes/boceto3.jpg">
<image src ="https://github.com/1502Pam/Project/blob/main/Im%C3%A1genes/boceto3.1.jpg">
<image src ="https://github.com/1502Pam/Project/blob/main/Im%C3%A1genes/despiece3.jpg">

## Tabla de valoración

<image src ="https://github.com/1502Pam/Project/blob/main/Im%C3%A1genes/evaluaci%C3%B3n_t%C3%A9cnica.jpeg">
<image src ="https://github.com/1502Pam/Project/blob/main/Im%C3%A1genes/evaluaci%C3%B3n_econ%C3%B3mica.jpeg">

## Proyecto óptimo

<image src ="https://github.com/1502Pam/Project/blob/main/Im%C3%A1genes/grafica_proyecto_optimo.jpeg">

## Conclusión del CS

Se ha optado por la segunda propuesta conceptual como la solución más apropiada. Esta elección se fundamenta en la accesibilidad de ciertos componentes, tales como las baterías, el cargador y/o el sensor, que son de dimensiones reducidas y pueden integrarse de manera eficiente en una prótesis diseñada para el pulgar o su entorno. En resumen, al aprovechar las ventajas de estos componentes en términos de tamaño y disponibilidad, esperamos lograr mejoras significativas en cuanto al tipo de agarre y la fuerza que la mano protésica pueda ejercer.

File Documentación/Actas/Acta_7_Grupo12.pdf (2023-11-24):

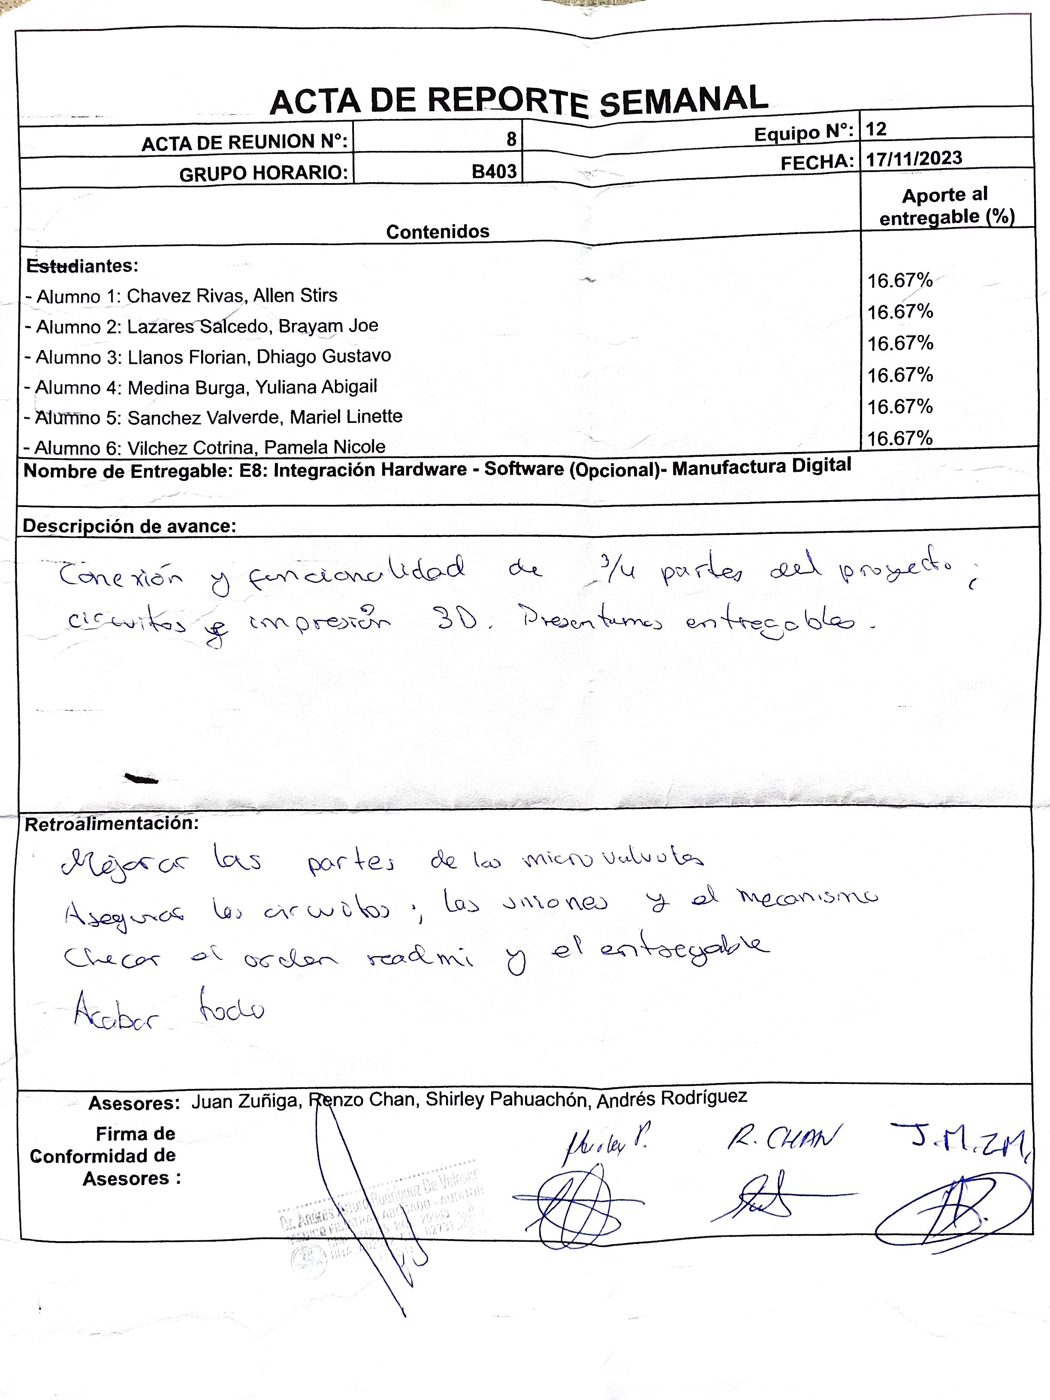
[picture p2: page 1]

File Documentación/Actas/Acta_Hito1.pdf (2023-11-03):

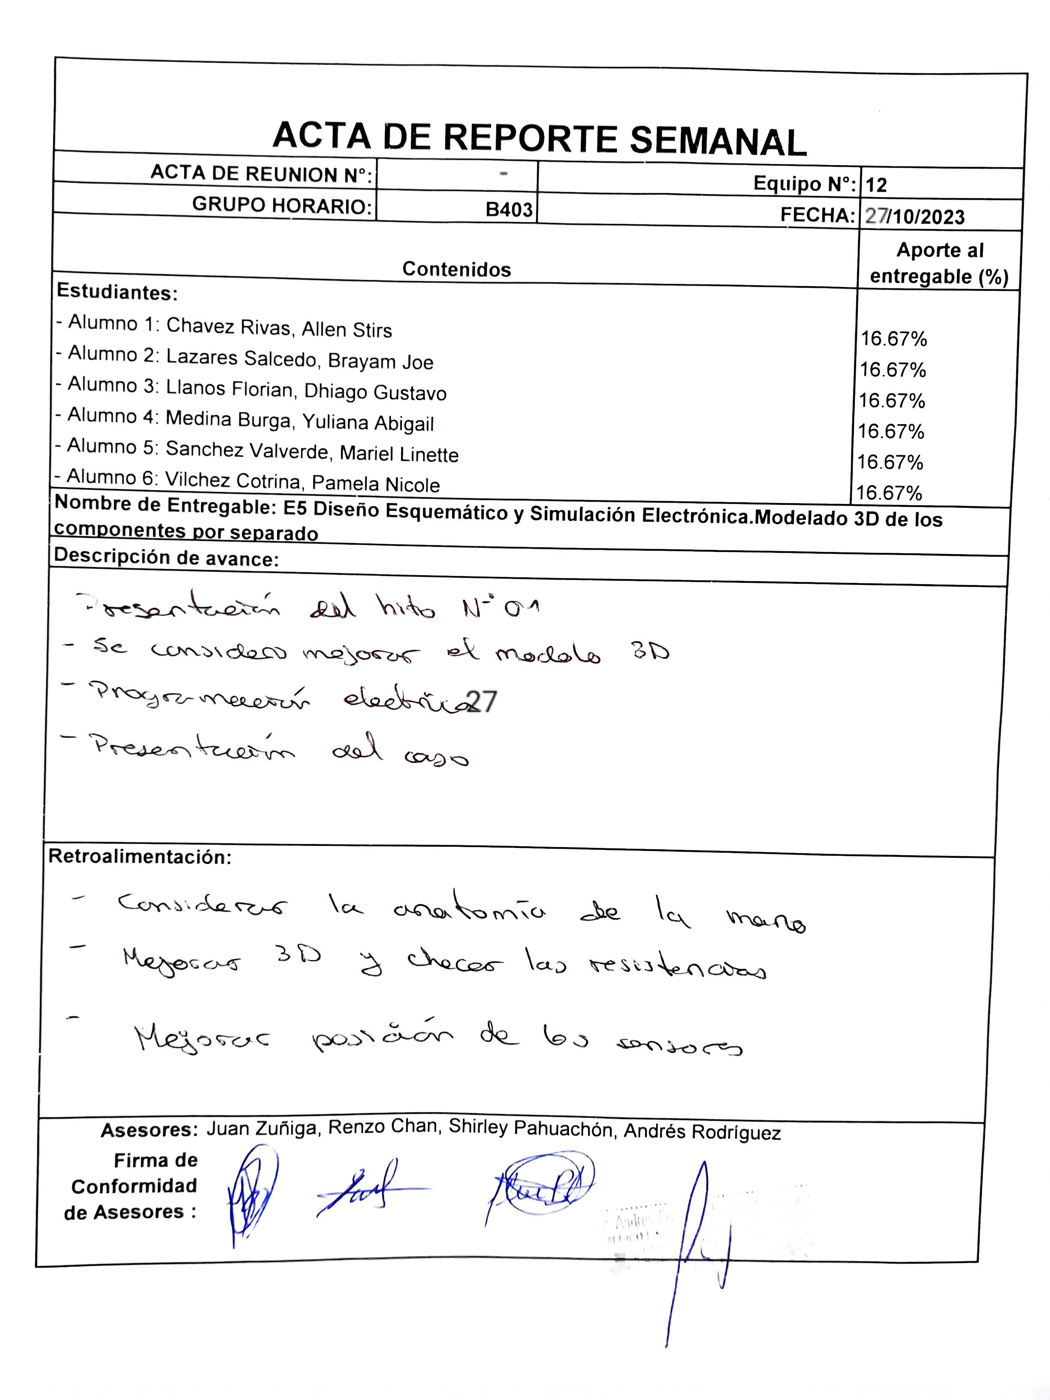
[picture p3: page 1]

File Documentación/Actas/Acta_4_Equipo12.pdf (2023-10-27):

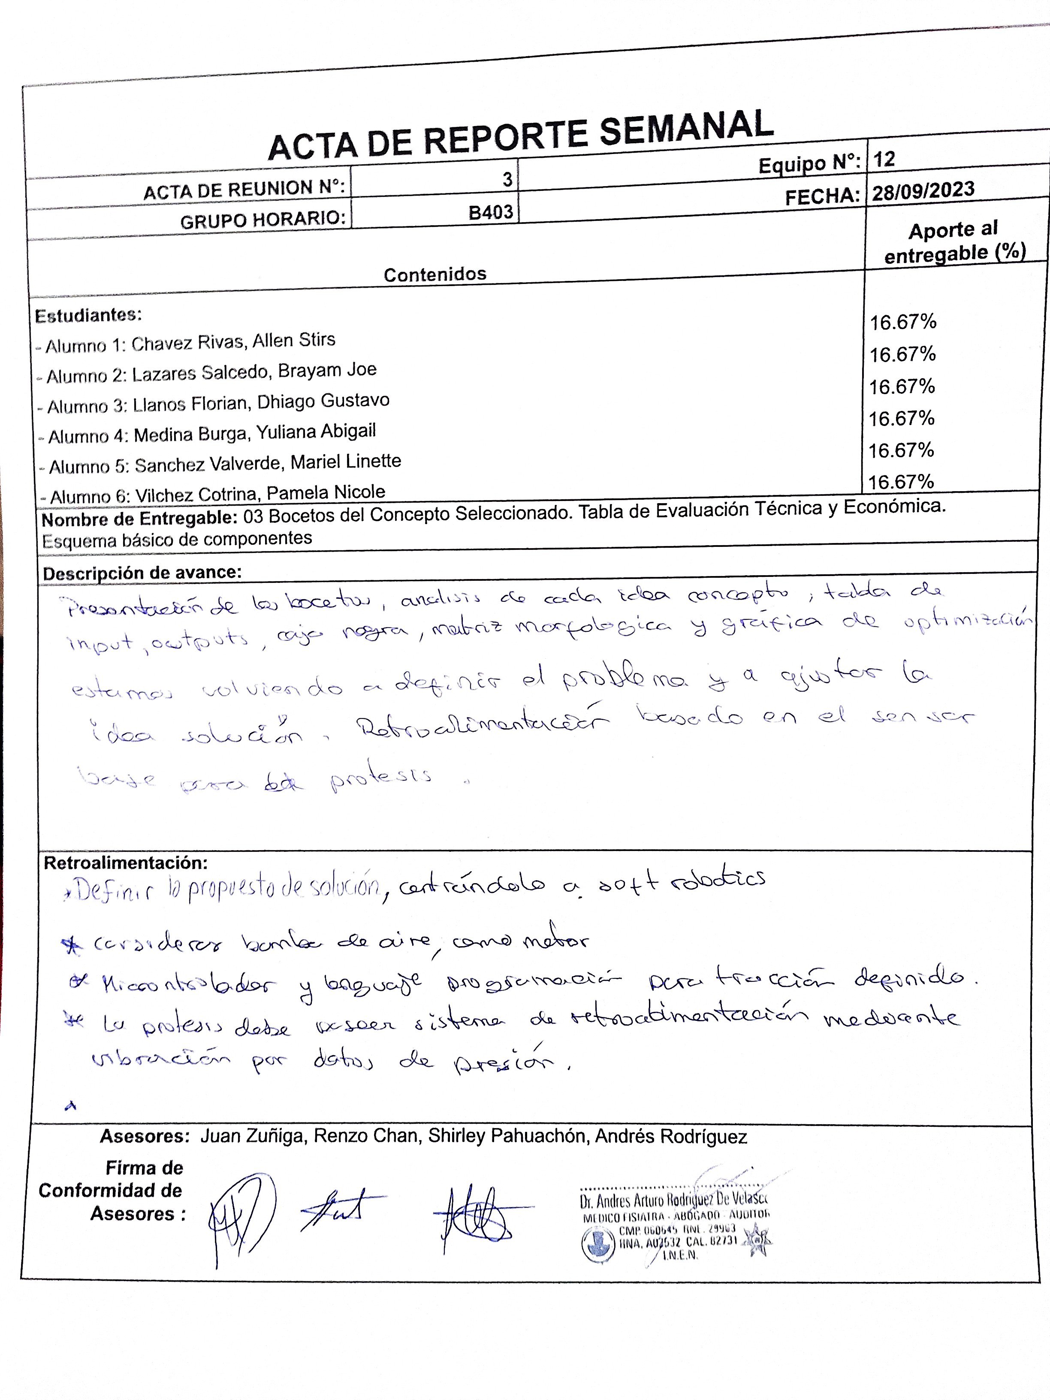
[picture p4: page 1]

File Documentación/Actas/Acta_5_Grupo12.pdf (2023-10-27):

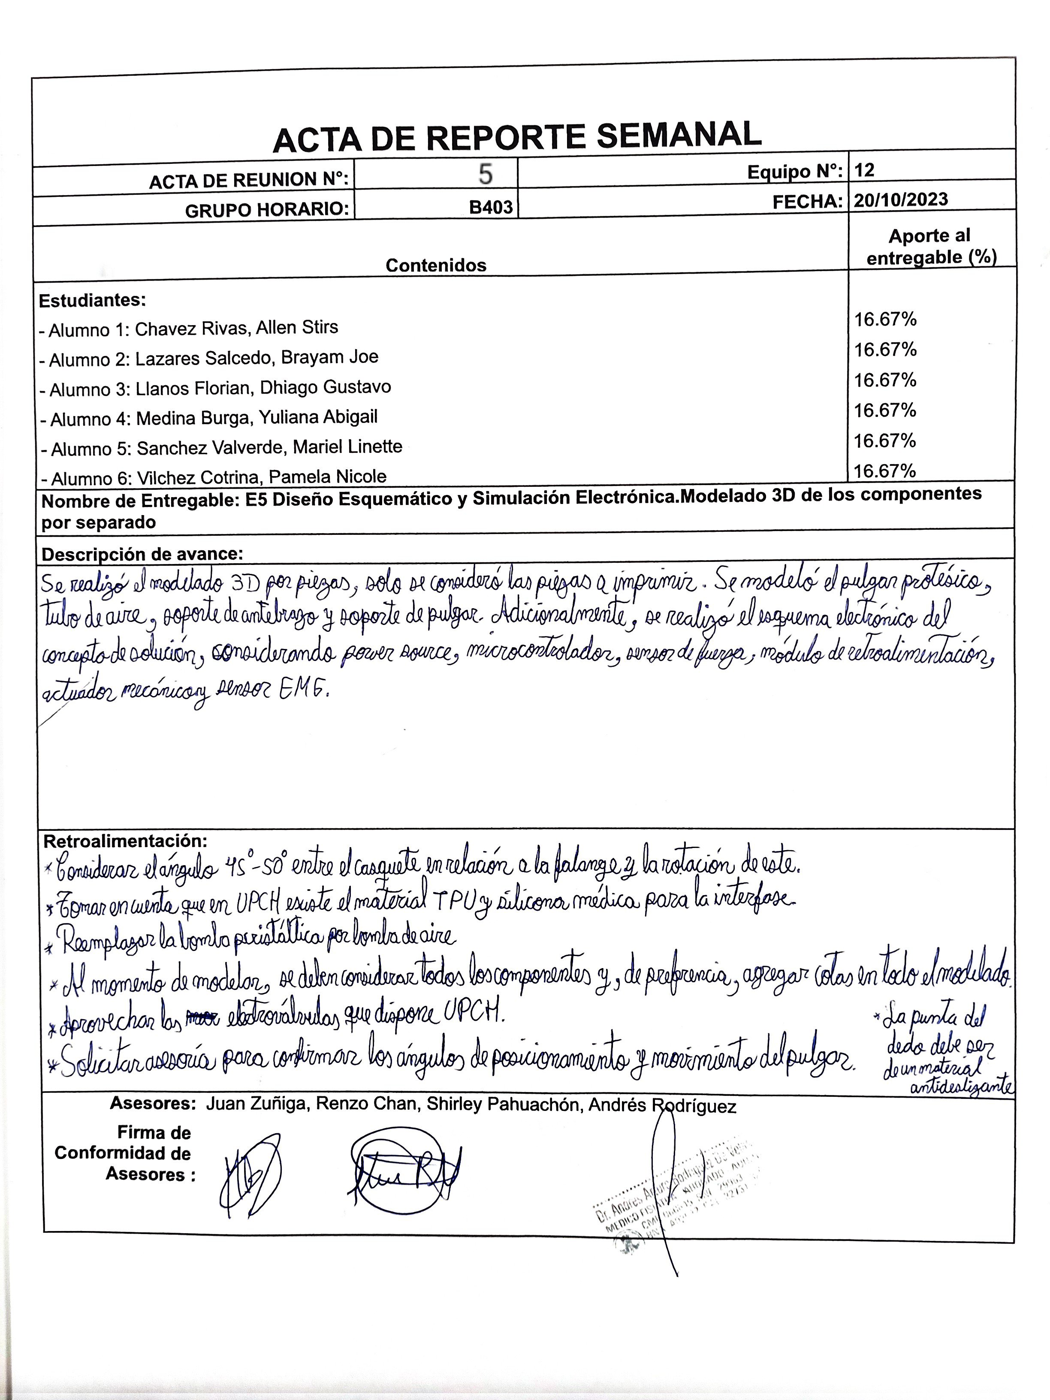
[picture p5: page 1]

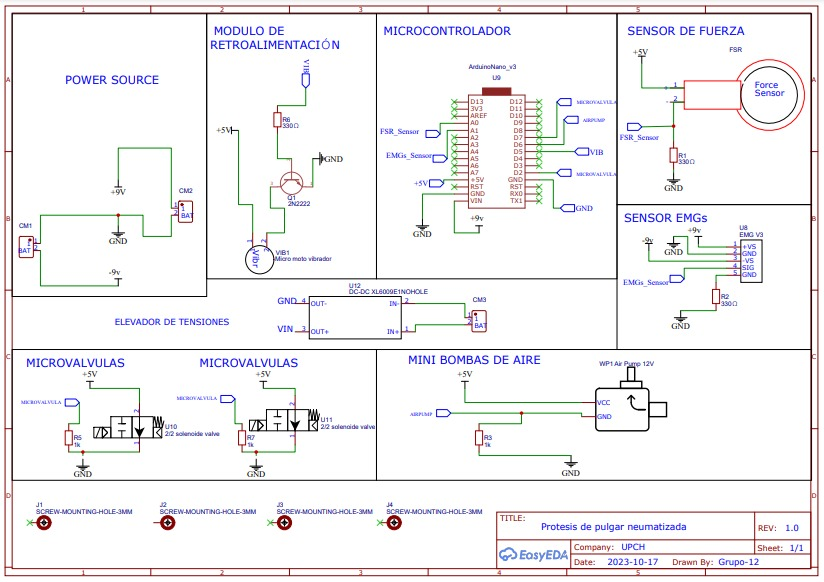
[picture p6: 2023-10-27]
Imágenes/Esquema_electronico_actualizado.png

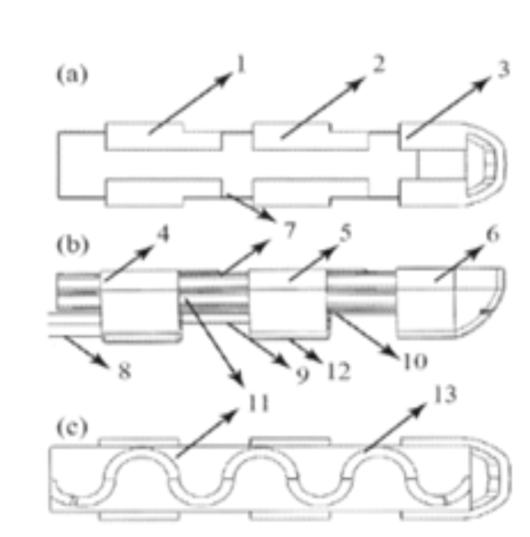
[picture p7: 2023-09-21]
Imágenes/protesis_mano.png

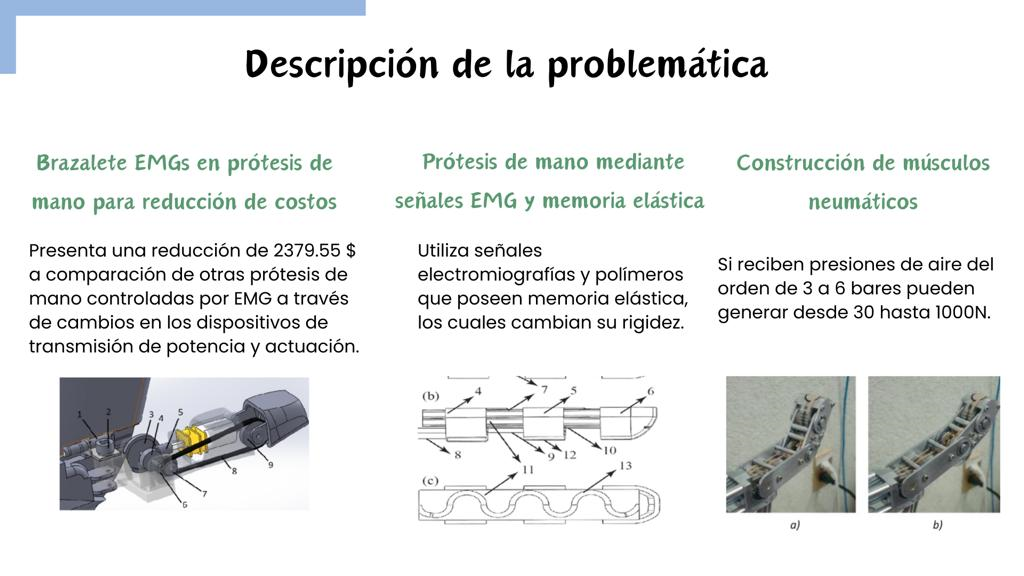
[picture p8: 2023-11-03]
Imágenes/hito_2.png

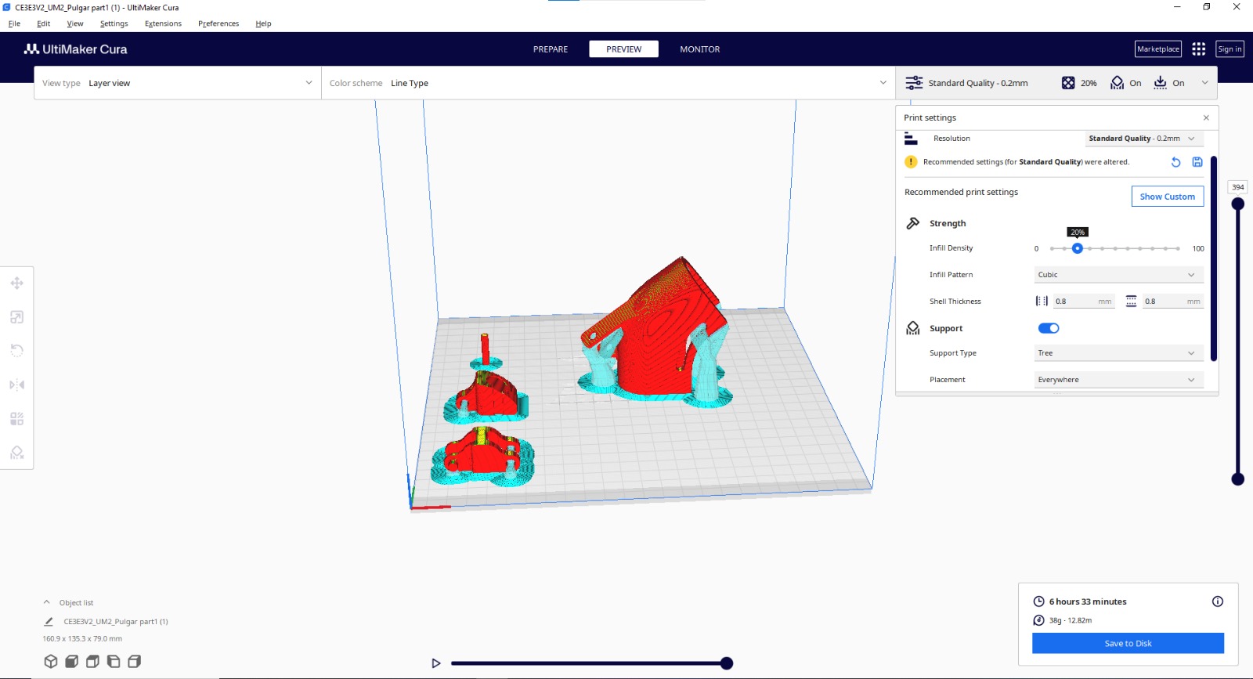
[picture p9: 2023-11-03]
Imágenes/pulgar.jpeg

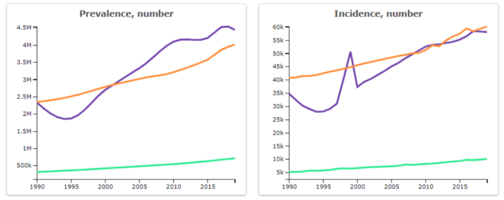
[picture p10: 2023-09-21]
Imágenes/B4.png

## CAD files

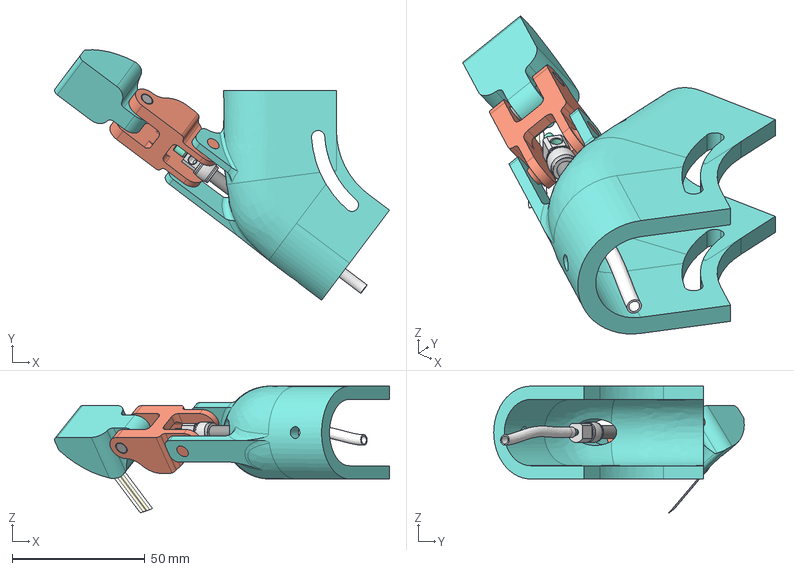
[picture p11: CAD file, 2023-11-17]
Hardware/Modelado digital/Pulgar_Grupo12.step
126.2 x 94.4 x 47.7 mm

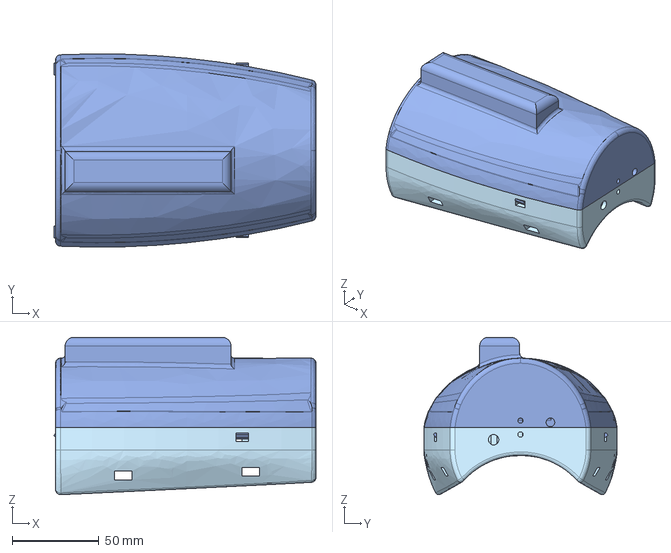
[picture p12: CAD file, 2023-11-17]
Hardware/Modelado digital/Muñequera1_Grupo12.step
150.9 x 111.3 x 90.7 mm

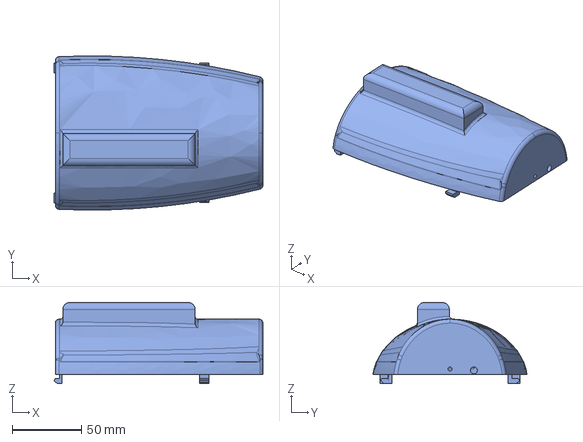
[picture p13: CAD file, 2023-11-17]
Hardware/Modelado digital/Muñequera2_Grupo12.step
150.9 x 111.3 x 58.5 mm

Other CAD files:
Hardware/Modelado digital/Muñequera2_Grupo12.stl

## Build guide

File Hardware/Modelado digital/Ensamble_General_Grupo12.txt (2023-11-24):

Explicación: La imagen muestra el diseño general sobre la idea general del diseño solución. Se aprecia la protesis conectada de manera superficial a la mano amputada, con el primer modelo del socket.

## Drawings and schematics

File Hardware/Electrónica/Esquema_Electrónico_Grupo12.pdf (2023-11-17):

SENSOR EMG | MICROCONTROLADOR | SENSOR DE FUERZA

## MODULO DE

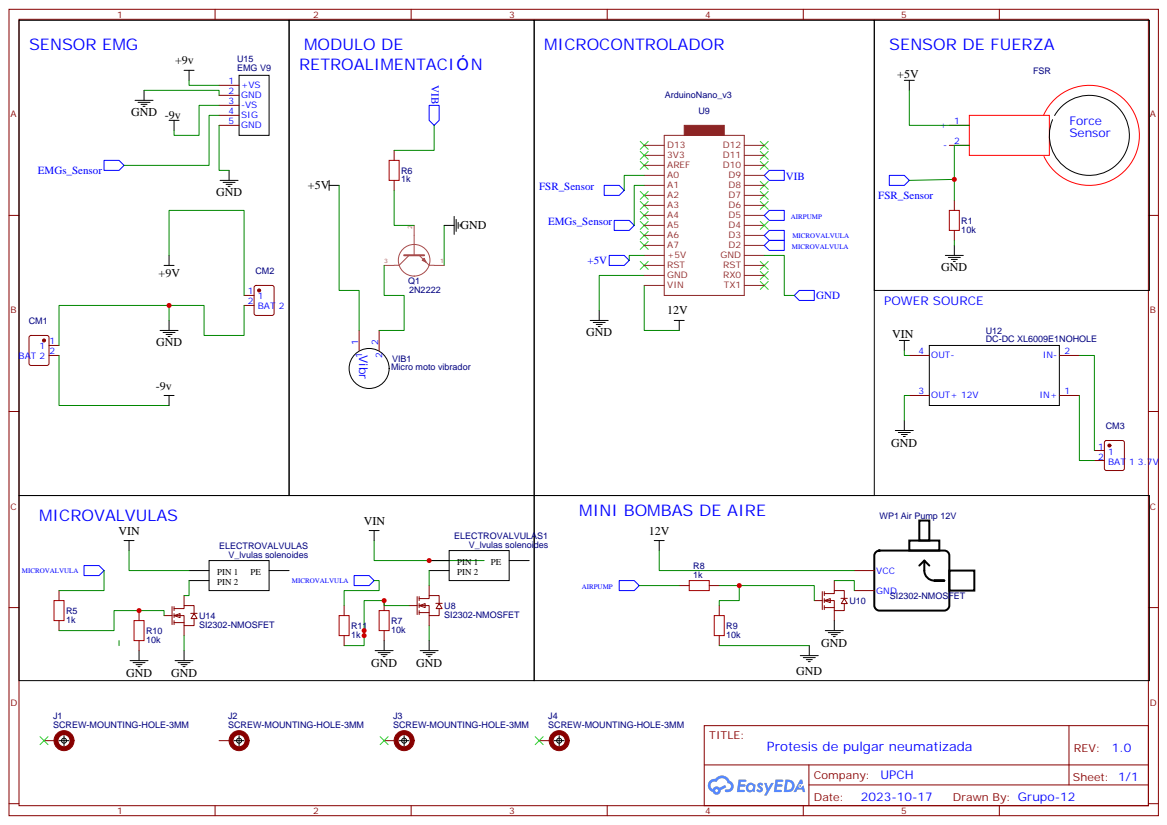
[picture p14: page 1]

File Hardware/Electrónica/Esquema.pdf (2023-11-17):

SENSOR EMG | MICROCONTROLADOR | SENSOR DE FUERZA

## MODULO DE

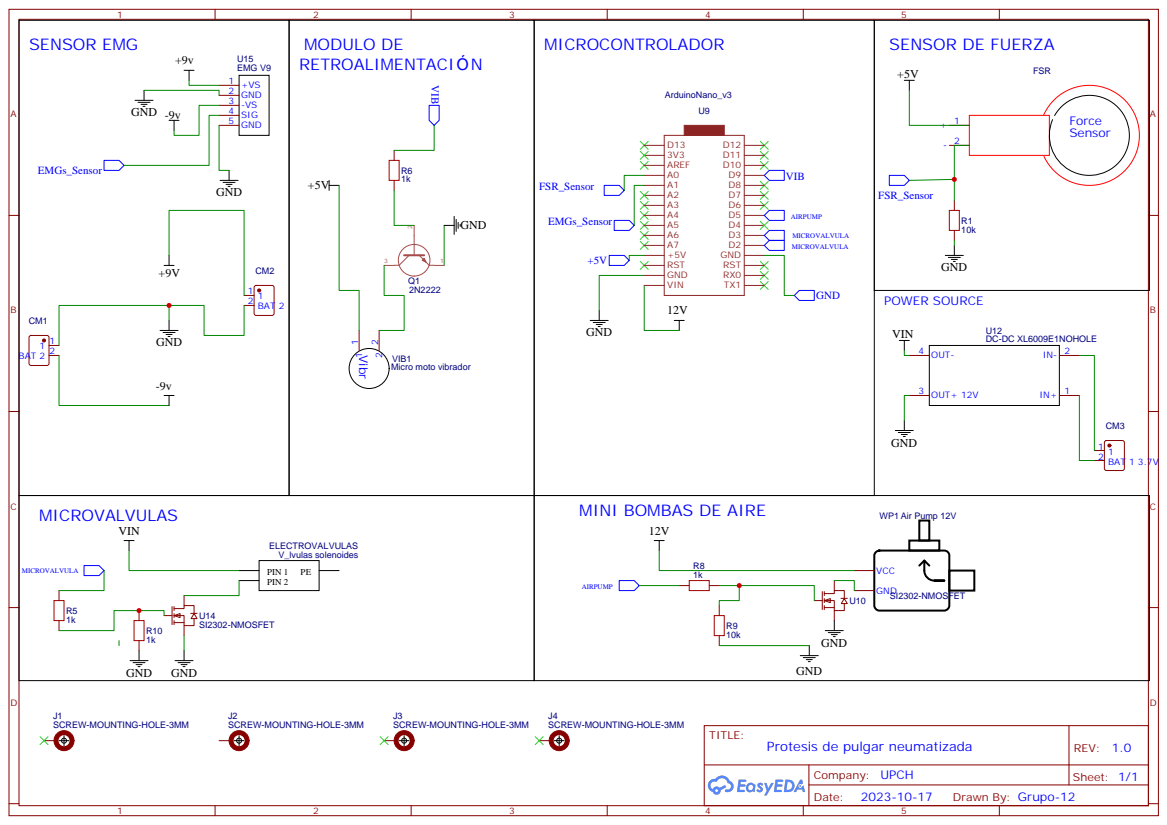
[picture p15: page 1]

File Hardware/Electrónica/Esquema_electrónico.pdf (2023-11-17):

MICROCONTROLADOR | SENSOR DE FUERZA

## POWER SOURCE

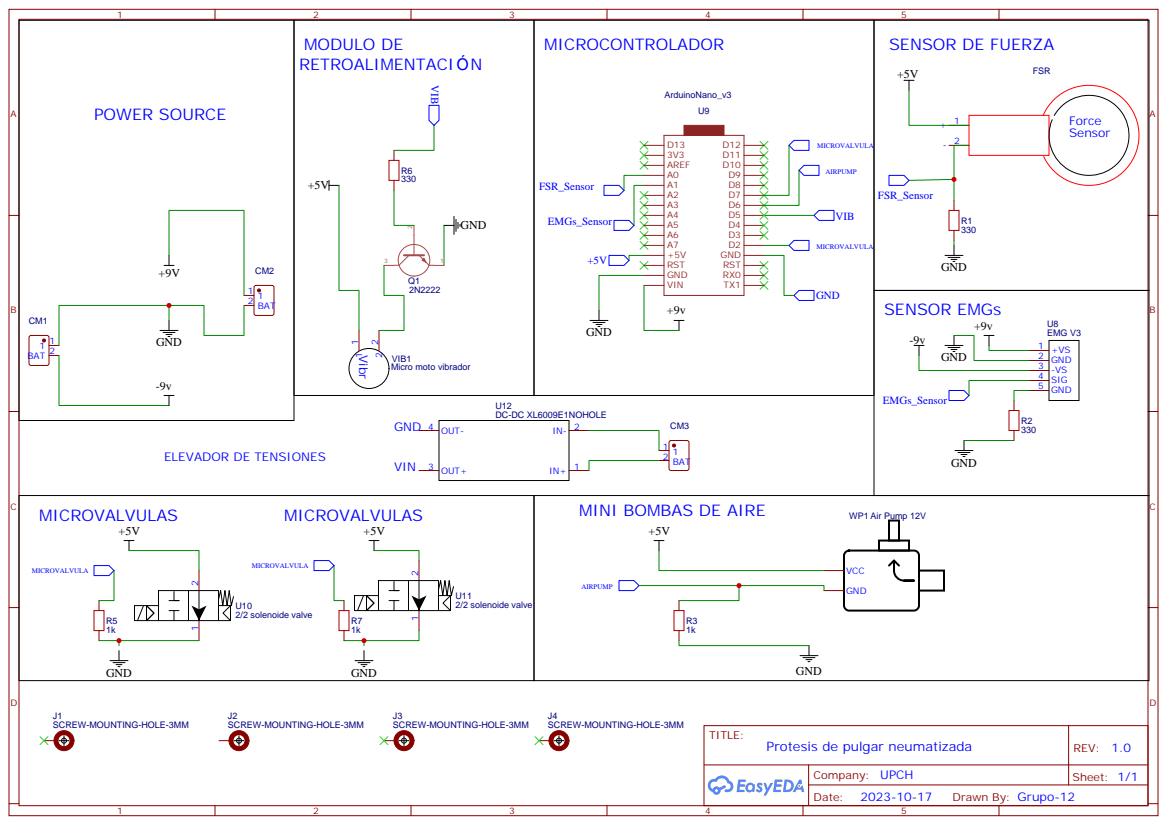
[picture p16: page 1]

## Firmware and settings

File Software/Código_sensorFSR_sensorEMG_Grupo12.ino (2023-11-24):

#define EMG_SENSOR_PIN A4       // Sensor EMG conectado al pin analógico A4
#define AIR_PUMP_PIN 5          // Bomba conectada al pin digital 5
#define VALVE1_PIN 2        // Válvula para microválvulas de aire conectada a bomba
#define VALVE2_PIN 7        // Válvula para expulsión de aire 
#define motorPin 6              // Pin del motor 
#define sensorpin A3            // Pin del sensor FSR
#define alpha 0.03 //factor de suavizado

//variables del emg
int sensor_EMG;
int contador=1; //diferenciar entre flexión/extensión
int val_filtrado = 0;
int sen_analog = 0;
const int x = 24; //cte entera
int periodo= 4000;
int periodo2= 4000;
unsigned long tiempoAhora=0;

//variables del fsr
int sensorFSR;
int tmap;
int i;
int auxSuma;
int promFSR;

void setup() {
  pinMode(EMG_SENSOR_PIN, INPUT);
  pinMode(AIR_PUMP_PIN, OUTPUT);
  //válvula 1
  pinMode(VALVE1_PIN, OUTPUT);
  //válvula 2
  pinMode(VALVE2_PIN, OUTPUT);
  pinMode(motorPin, OUTPUT);
  pinMode(sensorpin, INPUT);
  Serial.begin(9600);
}

void loop() {
    //contador =1; //siempre valor inicial =1

    // Sensor FSR
    for (i = 1; i <= 10; i++) {
        sensorFSR = analogRead(sensorpin);
        delay(10);
        auxSuma += sensorFSR;
    }
    promFSR = auxSuma / 10;
    auxSuma = 0;
  	//Serial.print("Sensor FSR: ");
    //Serial.println(sensorFSR);
    tmap = map(promFSR, 0, 1000, 10, 255);
    analogWrite(motorPin, tmap);
  
  // FILTRO EMA (Promedio móvil exponencial) para señal EMG
    sensor_EMG = analogRead(EMG_SENSOR_PIN);
    val_filtrado = (alpha * sensor_EMG)+((1-alpha)*val_filtrado); //valFiltrado de valor anterior
    //imprimir sensor EMG
  	//Serial.print("Sensor EMG: ");
    Serial.print(sensor_EMG);
    Serial.print(" , ");
    Serial.println(val_filtrado);
    //Serial.print(" , ");
    //Serial.println(contador);

  // Control de la bomba basado en el sensor EMG
    if (val_filtrado > x && contador == 1) {
    //se realiza agarre 
      digitalWrite(AIR_PUMP_PIN, HIGH);
      digitalWrite(VALVE1_PIN, HIGH);//válvula abierta
      digitalWrite(VALVE2_PIN, LOW);//válvula cerrada
      if(millis()> tiempoAhora + periodo){ //temporizador
        tiempoAhora=millis();
        digitalWrite(VALVE1_PIN, LOW); // Mantener agarre
        digitalWrite(AIR_PUMP_PIN, LOW);
        contador =2;
      }
      Serial.println("*Cierra Mano*");
      //Serial.print("Contador: ");
      //Serial.println(contador);
      
    } 
    else if (val_filtrado > x && contador == 2){
      Serial.println("*Abre Mano*");
      //Serial.print("Contador: ");
      //Serial.println(contador);
      if(millis()> tiempoAhora + periodo2){ //temporizador
        tiempoAhora=millis();
        //Realizar extensión del pulgar
        
 //valvula de la bomba cerrada
digitalWrite(VALVE1_PIN, LOW);
digitalWrite(VALVE2_PIN, HIGH);//abierta

       contador =1;
      }
    }
  delay(10);  
}

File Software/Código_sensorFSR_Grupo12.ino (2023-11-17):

#define motorPin 5
#define sensorpin A0
int sensorFSR;
int tmap;
int i;
int auxSuma;
int promFSR;
void setup(){
 pinMode(motorPin, OUTPUT);
 pinMode(sensorpin, INPUT);
 Serial.begin(9600);//iniciación de comunicación serial a 9600 baudios
}

void loop(){
  //for (int thisPin = 7; thisPin >= 2; thisPin--) {
  for (i=1;i<=10;i++){
  sensorFSR=analogRead(A0);
  delay(10);
  auxSuma += sensorFSR;
  }
  promFSR = auxSuma/10;
 auxSuma=0;
 Serial.println(sensorFSR);
 tmap= map(promFSR, 0, 1000, 10, 255);
  analogWrite(motorPin, tmap);
  delay(10);
}

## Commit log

2023-08-29 Create README.md
    Avance de presentación del proyecto
2023-08-31 subir logo de equipo
2023-09-01 actualización de imagen
2023-09-14 actualización de imágenes
2023-09-14 Update entregables.txt
    Tabla de estado del arte utilidad e inveción
2023-09-14 Imagenes de patentes de utilidad e invención
2023-09-14 Update entregables.txt
    adicion de imagenes
2023-09-29 tabla de valoracion
2023-11-17 Actualización
    [Muñequera_1.step, Muñequera_2.step, Muñequera_2.stl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]
